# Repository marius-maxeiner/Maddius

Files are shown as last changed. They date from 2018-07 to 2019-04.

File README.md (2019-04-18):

# Maddius
_English:_

ALPHA

The Maddius Main, built by Marius and Eddie.

Maddius is an Open - Source midi controller, you can build your own.
The idea is to share our code, 3d files and bill of material with the internet so the topic of midi controllers can be better understood.
Maddius is split in different Modules you can build so it fits with your setup, the i2c signal gets translated to midi by the Teensy 3.6 inside of the Maddius Main.
If you want more informations on the expansions for Maddius feel free to look inside thier respective folder.
Because the Maddius Main is the converter to Midi we recommend to start there.

Ever got tired of over complicated Dmx Controller or Light Setups in your favorite bar or club? You are working sometimes as a hobby technican? Dont worry no more, even better, impress your boss and show them your newly built Maddius Main! Controlling and adapting to your setup! Need 8 Fader and Blind Buttons? No problem! Need another expansions with scene selection or bank switching? We got you covered. Only want to build your own Midi Controller? Maybe our code is just for you!
Want to know how to wire a controller? Check out our diagramms!

We hope you have fun building and coding!

Greetings, Marius & Eddie.

_German:_

ALPHA

Der Maddius Main, gebaut von Marius und Eddie.

Maddius ist ein Open - Source Midi Controller, den du dir selbst bauen kannst.
Die Idee hinter der Sache ist es, unseren Code, 3D Modelle und eine Liste der gebrauchten Materialen im Internet zu veröffentlichen, damit das Thema Midi-Controller besser verstanden werden kann. Maddius ist aufgeteilt in verschiedene Module, die mit einer i2c Verbindung kommunizieren. Das Herzstück bildet hierbei der Maddius Main, da er alle Signale mithilfe eines Teensy 3.6 zu Midi konvertiert.
Wenn du mehr Informationen zu den einzelnen Modulen haben möchtest, kannst du dich gerne in den dazugehörigen Ordnern umsehen.
Allerdings empfehlen wir beim Maddius Main zu starten.

Bist du genervt von komplizierten Dmx Controllern oder Licht Setup´s in deiner geliebten Bar oder deines beliebeten Club´s? Arbeitest du manchmal als ein Hobby-Techniker? Mach dir keinen Kopf, noch besser, beeindrucke deinen Chef und zeige ihm deinen neu gebauten Maddius DMX Kontroller der Anpassbar auf dein Setup ist! Brauchst du 8 Fader und Blind Buttons? Kein Problem! Brauchst du Erweiterungen und auswählbare Scenen oder Layer switching? Wir haben alles für dich da. Möchtest du nur deinen eigenen Midi Controller bauen? Dann ist vielleicht unser Code genau das richtige für dich!
Möchtest du nur wissen, wie ein Controller verkabelt wird? Check unsere Diagramme!

Wir hoffen du hast Spaß beim nachbauen und programmieren!

Grüße, Marius & Eddie.

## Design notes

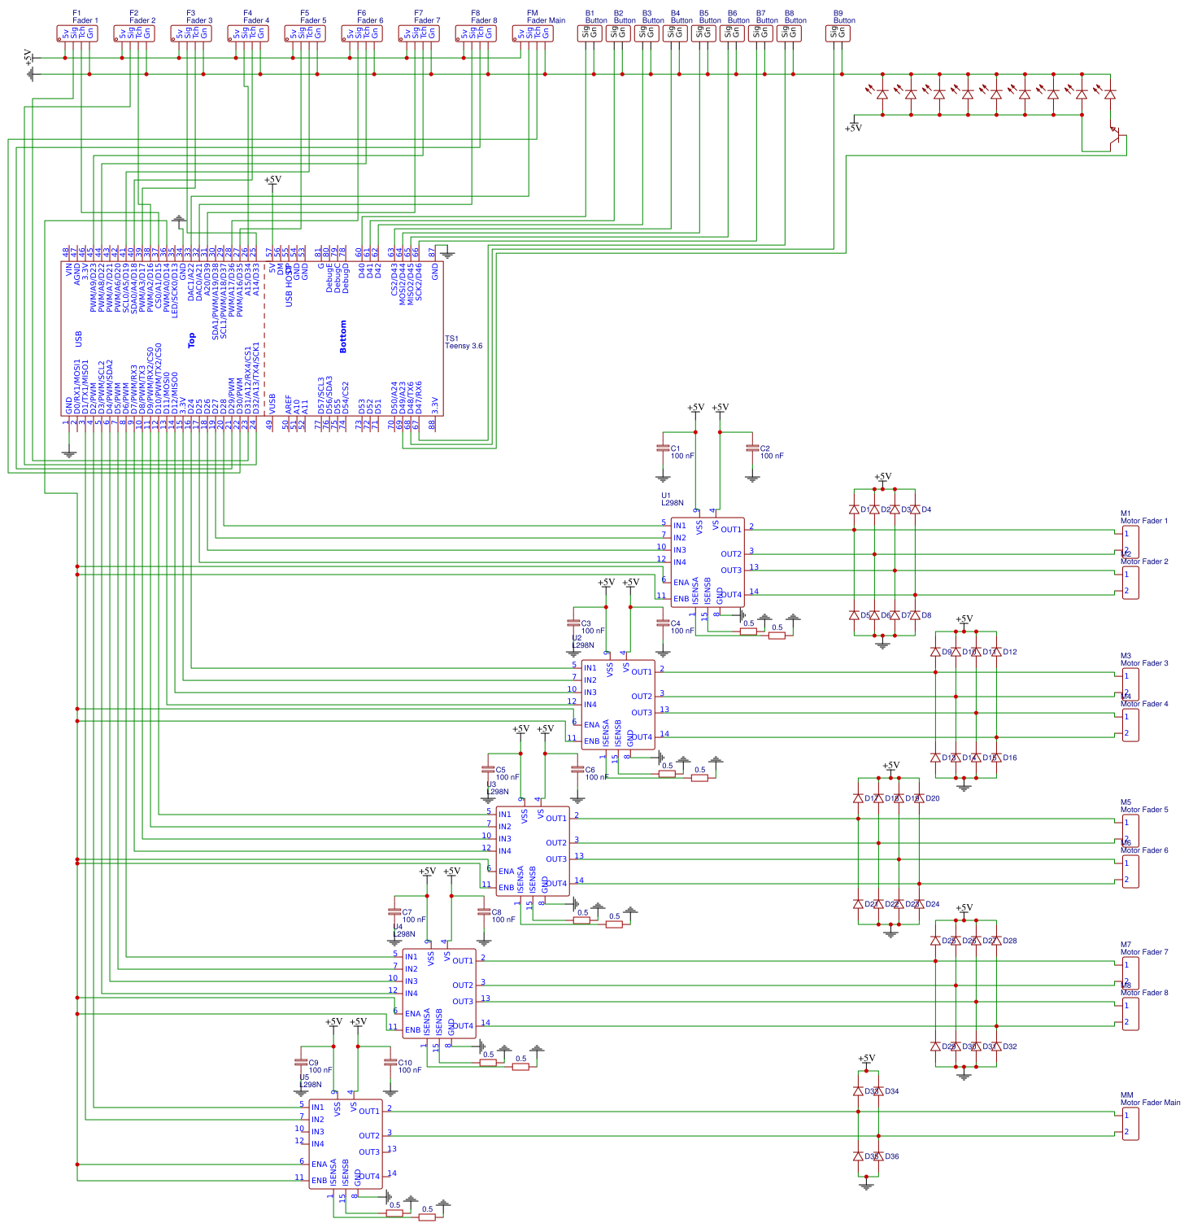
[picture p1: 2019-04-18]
Main/Schematic_Maddius-Main.png

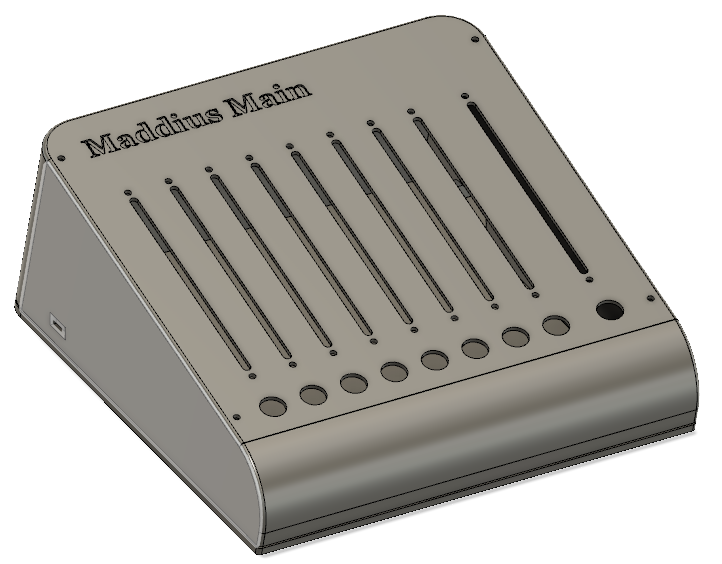
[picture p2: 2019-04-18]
Main/Maddius Main.png

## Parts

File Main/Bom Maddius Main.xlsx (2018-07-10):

BOM | Maddius Main
 | Name | Link | Price
 | Motor Fader | https://www.thomann.de/de/yamaha_ls_901vmotorised_fader.htm?glp=1 | 19.90 €
 | Teensy 3.6 | https://www.amazon.de/Teensy-3-6/dp/B01MG2PYYP | 42.99 €
 | Buttons | https://www.amazon.de/Larcele-Wasserdicht-Drücken-Druckknöpfe-JSANKG-02/dp/B075YPVY56?s=aps | 17.99 €
 | Motor Controller | https://www.amazon.de/Channel-Treiberplatine-Geschwindigkeit-Stepper-Ladicha/dp/B077MBSF2N?s=diy

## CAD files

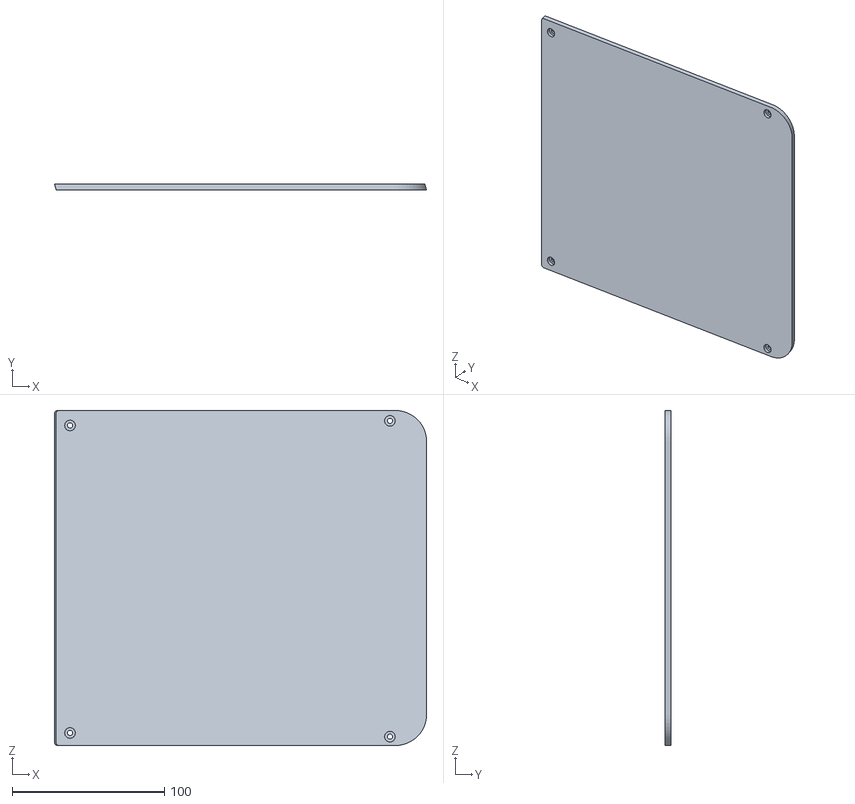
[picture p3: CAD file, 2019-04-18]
Main/3D Models/Maddius Main Base.stl
244.1 x 4.00 x 219.9

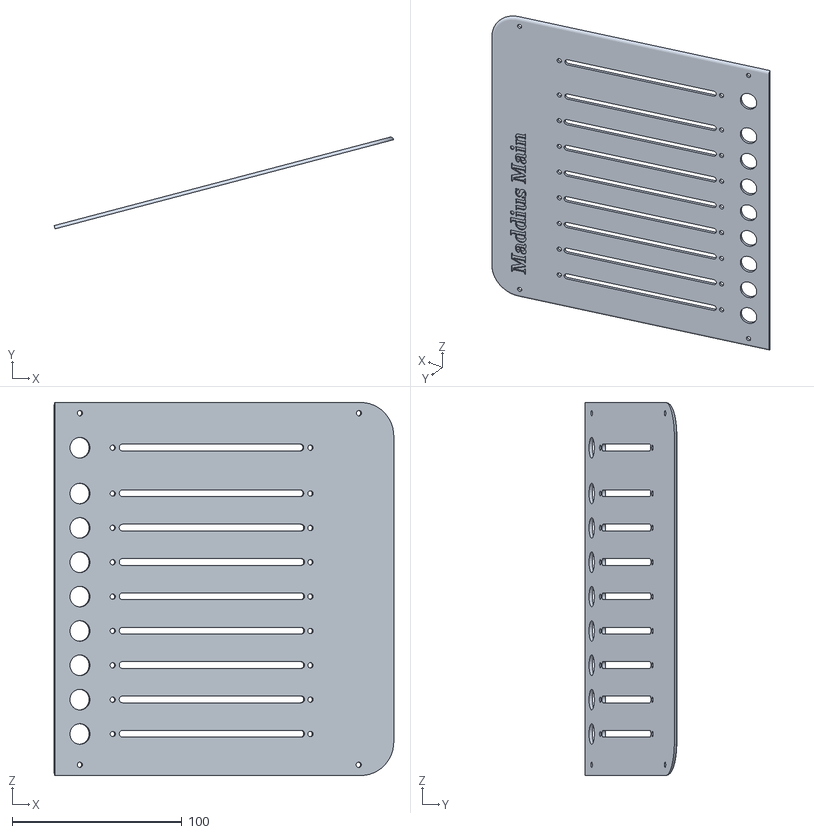
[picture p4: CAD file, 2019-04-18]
Main/3D Models/Maddius Main Cover.stl
200.2 x 54.1 x 219.9

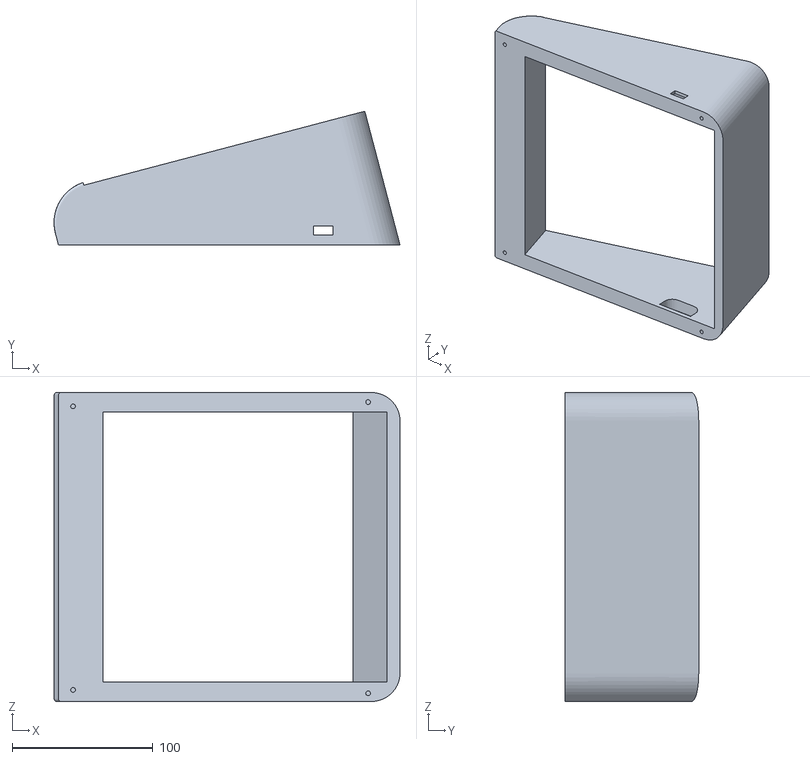
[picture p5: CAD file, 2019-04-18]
Main/3D Models/ Maddius Main Case.stl
246.1 x 95.0 x 219.9

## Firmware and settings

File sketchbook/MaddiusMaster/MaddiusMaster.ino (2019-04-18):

<<<<<<< HEAD
/* Belegung	Pin Name	Pin Number	Spice Number
	VBAT	1	1
	5V	2	2
	USBD2-	3	3
	USBD2+	4	4
	USBD1-	5	5
	USBD1+	6	6
Fader 5	A10	7	7
Fader 6	A11	8	8
	GND	9	9
Btn 1	0	10	10
Btn 2	1	11	11
Btn LED 1	2	12	12
Btn LED 2	3	13	13
Btn LED 3	4	14	14
Btn LED 4	5	15	15
Btn LED 5	6	16	16
Btn LED 6	7	17	17
Btn LED 7	8	18	18
Btn LED 8	9	19	19
Btn LED 9	10	20	20
Motor 1 B	11	21	21
Motor 1 A	12	22	22
Motor 5 B	40	23	23
Motor 2 B	24	24	24
Motor 3 B	25	25	25
Motor 3 A	26	26	26
Motor 4 A	27	27	27
Motor 4 B	28	28	28
Touch 8	29	29	29
Touch 9	30	30	30
Fader 1	31/A12	31	31
Fader 2	32/A13	32	32
Motor 5 A	41	33	33
Motor 6 A	42	34	34
Motor 6 B	43	35	35
Motor 7 B	44	36	36
Motor 7 B	45	37	37
Motor 8 A	46	38	38
Motor 8 B	47	39	39
Motor 9 B	48	40	40
Btn 3	49/A23	41	41
Btn 4	50/A24	42	42
Motor 9 A	51	43	43
Btn 5	52	44	44
Btn 6	53	45	45
Btn 7	54	46	46
Btn 8	55	47	47
I2C	56	48	48
Standby	33/A14	49	49
Motor 2 A	34/A15	50	50
	35/A16	51	51
Motor Speed	36/A17	52	52
I2C	37/A18	53	53
I2C	38/A19	54	54
Fader 7	39/A20	55	55
Fader 3	A21	56	56
Fader 4	A22	57	57
I2C	57	58	58
Power/Sys LED	13 (LED)	59	59
Fader 8	14/A0	60	60
Touch 1	15/A1	61	61
Touch 2	16/A2	62	62
Touch 3	17/A3	63	63
Touch 4	18/A4	64	64
Touch 5	19/A5	65	65
Fader 9	20/A6	66	66
Btn 9	21/A7	67	67
Touch 6	22/A8	68	68
Touch 7	23/A9	69	69
	3V3	70	70
	AGND	71	71
Main Power	VIN	72	72
	GND	73	73
	VUSB	74	74
	PRGM	75	75
	RESET	76	76
	AREF	77	77
	DBGEN	78	78
	SWCLK	79	79
	SWDIO	80	80
	MT1	81	81
	MT2	82	82
*/
=======
//This is the Code for the Maddius Main Controller, built by Marius and Eddie.
//We hope you have fun editing and using this Code for yourself.

>>>>>>> 7a19cae50ffcc8ba62d0dede8335053ce0ca0dc0


//________Including Library´s____________
#include <Wire.h> // I2C
// #include <ClickEncoder.h>
#include <TimerOne.h>
#include <ControlPanel.h>

//________Setting Defines________________
#define DEVMODE true

//________Setting Pins___________________
//MotorA motor1(3, 4, 2);

// Button Digi/LED PWM // 
// B1 0 / 2
Button button1(0);
// B2 1 / 3
Button button2(1);
/*// B3 55 / 4
Button button3(55);
// B4 14 / 31
Button button4(14);
// B5 35 / 6 // A16 / 
Button button5(35);
// B6 34 / 7 // A15 /
Button button6(34);
// B7 39 / 8 // A20
Button button7(39);
// B8 49 / 9 // A23
Button button8(49);
// B9 50 / 10 // A24
Button button9(50);*/

// Motor

// FADER Analog / Touch
// F1
Fader fader1(31, 15, new MotorB(11, 12, 36, 33)); // , new MotorPWM(2, 3)
// F2
Fader fader2(32, 16, new MotorB(34, 24, 36, 33));
// F3
Fader fader3(A21, 17, new MotorB(25, 26, 36, 33));
// F4
Fader fader4(A22, 18, new MotorB(27, 28, 36, 33));
// F5
Fader fader5(A10, 19, new MotorB(40, 41, 36, 33));
// F6
Fader fader6(A11, 22, new MotorB(42, 43, 36, 33));
// F7 
Fader fader7(39, 23, new MotorB(44, 45, 36, 33));
// F8
Fader fader8(14, 29, new MotorB(46, 47, 36, 33));
// F9
Fader fader9(20, 30, new MotorB(48, 51, 36, 33));

// Motoren PWM: 52
// M1 12 / 11

// Fader 1 fader1(10, 30, new MotorA(3, 4, 2));

// Fader fader2(A2, A3); // , new MotorPWM(4, 5)



//int pwmCircleCount = 0;
//byte motorspeed = 0;

// ClickEncoder* encoder;
// int16_t last, value;

// int16_t mouseTimeout = 0;

// JoyStick* joy1;
void setup() {
<<<<<<< HEAD
  // encoder = new ClickEncoder(A20, A19, A18);
  // joy1 =  new JoyStick(A17,A16);
  // put your setup code here, to run once
  if (DEVMODE) {
    pinMode(LED_BUILTIN, OUTPUT);
    pinMode(LED_BUILTIN, INPUT_PULLUP);
    // Serial.begin(57600); // start serial for output
=======
  encoder = new ClickEncoder(A20, A19, A18);
  joy1 =  new JoyStick(A17,A16);
  if (DEVMODE) {
    pinMode(LED_BUILTIN, OUTPUT);
    pinMode(LED_BUILTIN, INPUT_PULLUP);
    pinMode(52, OUTPUT);
    // ___SERIAL_BEGIN____
    Serial.begin(57600);
>>>>>>> 7a19cae50ffcc8ba62d0dede8335053ce0ca0dc0
    // Serial.println("Start Maddius Master");
  }

  // __Init Midi read functions__
  usbMIDI.setHandleNoteOff(myNoteOff);
  usbMIDI.setHandleNoteOn(myNoteOn);
  usbMIDI.setHandleAfterTouchPoly(myAfterTouchPoly);
  usbMIDI.setHandleControlChange(myControlChange);

  //fader1._valueTarget = 800;

  // Timer1.initialize(1000);
  // Timer1.attachInterrupt(timerIsr);
  // Motoren PWM: 52
// M1 12 / 11
  /* byte _motorUpIOPin = 11;
   byte _motorDownIOPin = 12;
   byte _motorSpeedPWM = 52;
  delay(1000);
  // Motor Test
  pinMode(_motorUpIOPin, OUTPUT);
  pinMode(_motorDownIOPin, OUTPUT);
  analogWrite(_motorSpeedPWM , 150);
  delay(1000);
  digitalWrite(_motorUpIOPin, HIGH);
  digitalWrite(_motorDownIOPin, LOW);
  delay(1000);
  digitalWrite(_motorUpIOPin, LOW);
  digitalWrite(_motorDownIOPin, HIGH);
  delay(1000);
  digitalWrite(_motorUpIOPin, HIGH);
  digitalWrite(_motorDownIOPin, LOW);
  delay(1000);
  digitalWrite(_motorUpIOPin, LOW);
  digitalWrite(_motorDownIOPin, HIGH);
  delay(1000);*/



}

/* void timerIsr() {
  // encoder->service();
  
  if(mouseTimeout > 10){
    joy1->update();
    if(joy1->_humanChanged){
      Serial.print(" X: ");
      Serial.print(joy1->_xValue);
      Serial.print(" Y: ");
      Serial.println(joy1->_yValue);
      usbMIDI.sendControlChange(96, joy1->_xValue >> 3, 1);
      usbMIDI.sendControlChange(97, joy1->_yValue >> 3, 1);
    }
    mouseTimeout = 0;
  }
  mouseTimeout++;
} */
void loop() {

  
  // BUTTON UPDATE
  short b1 = button1.update();
  short b2 = button2.update();
  /*short b3 = button3.update();
  short b4 = button4.update();
  short b5 = button5.update();
  short b6 = button6.update();
  short b7 = button7.update();
  short b8 = button8.update();
  short b9 = button9.update();*/

  // FADER UPDATE




  short f1 = fader1.update();
          //Serial.println("f1_humanChanged");
        //Serial.println(fader1.readTouch());



  short f2 = fader2.update();
  short f3 = fader3.update();
  short f4 = fader4.update();
  short f5 = fader5.update();
  short f6 = fader6.update();
  short f7 = fader7.update();
  short f8 = fader8.update();
  short f9 = fader9.update();

  

  byte val1 = f1 / 8;
  byte val2 = f2 / 8;
  byte val3 = f3 / 8;
  byte val4 = f4 / 8;
  byte val5 = f5 / 8;
  byte val6 = f6 / 8;
  byte val7 = f7 / 8;
  byte val8 = f8 / 8;
  byte val9 = f9 / 8;
  
  /*if (DEVMODE) {
      //Serial.println(fader1.readAnalog());
      //Serial.println(touchRead(15));

     if(button1._humanChanged){
        Serial.println("button1._humanChanged");
        Serial.println(b1);
        usbMIDI.sendControlChange(64, b1, 1);
      }
      if(button2._humanChanged){
        Serial.println("button2._humanChanged");
        Serial.println(b2);
        usbMIDI.sendControlChange(65, b2, 1);
      }
      /*if(button3._humanChanged){
        Serial.println("button3._humanChanged");
        Serial.println(b3);
        usbMIDI.sendControlChange(66, b3, 1);
      }
      if(button4._humanChanged){
        Serial.println("button4._humanChanged");
        Serial.println(b4);
        usbMIDI.sendControlChange(67, b4, 1);
      }
      if(button5._humanChanged){
        Serial.println("button5._humanChanged");
        Serial.println(b5);
        usbMIDI.sendControlChange(68, b5, 1);
      }
      if(button6._humanChanged){
        Serial.println("button6._humanChanged");
        Serial.println(b6);
        usbMIDI.sendControlChange(69, b6, 1);
      }
     if(button7._humanChanged){
        Serial.println("button7._humanChanged");
        Serial.println(b7);
        usbMIDI.sendControlChange(70, b7, 1);
      }
      if(button8._humanChanged){
        Serial.println("button8._humanChanged");
        Serial.println(b8);
        usbMIDI.sendControlChange(71, b8, 1);
      }
      if(button9._humanChanged){
        Serial.println("button9._humanChanged");
        Serial.println(b9);
        usbMIDI.sendControlChange(72, b9, 1);
        _humanChanged = false;
      }*/
// Serial.print("T1: ");
// Serial.println(fader1.readTouch());
// Serial.print("F1: ");
//Serial.println(fader1.readAnalog());


      // FADER 
      /*if(fader1._humanChanged){
        Serial.println("f1_humanChanged");
        Serial.println(fader1.readTouch());
        // Serial.println(f1);
        Serial.println(fader1.readAnalog());
        usbMIDI.sendControlChange(12, val1, 1);
      }
     if(fader2._humanChanged){
        Serial.println("f2_humanChanged");
        Serial.println(fader2.readTouch());
        Serial.println(f2);
        Serial.println(fader2._valueTarget);
        usbMIDI.sendControlChange(13, val2, 1);
      }
      if(fader3._humanChanged){
        Serial.println("f3_humanChanged");
        Serial.println(fader3.readTouch());
        Serial.println(f3);
        Serial.println(fader3._valueTarget);
        usbMIDI.sendControlChange(14, val3, 1);
      }
      if(fader4._humanChanged){
        Serial.println("f4_humanChanged");
        Serial.println(fader4.readTouch());
        Serial.println(f4);
        Serial.println(fader4._valueTarget);
        usbMIDI.sendControlChange(15, val4, 1);
      }
      if(fader5._humanChanged){
        Serial.println("f5_humanChanged");
        Serial.println(fader5.readTouch());
        Serial.println(f5);
        Serial.println(fader5._valueTarget);
        usbMIDI.sendControlChange(16, val5, 1);
      }
      if(fader6._humanChanged){
        Serial.println("f6_humanChanged");
        Serial.println(fader6.readTouch());
        Serial.println(f6);
        Serial.println(fader6._valueTarget);
        usbMIDI.sendControlChange(17, val6, 1);
      }
      if(fader7._humanChanged){
        Serial.println("f7_humanChanged");
        Serial.println(fader7.readTouch());
        Serial.println(f7);
        Serial.println(fader7._valueTarget);
        usbMIDI.sendControlChange(18, val7, 1);
      }
      if(fader8._humanChanged){
        Serial.println("f8_humanChanged");
        Serial.println(fader8.readTouch());
        Serial.println(f8);
        Serial.println(fader8._valueTarget);
        usbMIDI.sendControlChange(19, val8, 1);
      }
      if(fader9._humanChanged){
        Serial.println("f9_humanChanged");
        Serial.println(fader9.readTouch());
        Serial.println(f9);
        Serial.println(fader9._valueTarget);
        usbMIDI.sendControlChange(20, val9, 1);
      }
  }

  // value += encoder->getValue();
  
  /*if (value != last) {
    last = value;
    Serial.print("Encoder Value: ");
    Serial.println(value);
  }*/

  /* ClickEncoder::Button b = encoder->getButton();
  if (b != ClickEncoder::Open) {
    Serial.print("Button: ");
    #define VERBOSECASE(label) case label: Serial.println(#label); break;
    switch (b) {
      VERBOSECASE(ClickEncoder::Pressed);
      VERBOSECASE(ClickEncoder::Held)
      VERBOSECASE(ClickEncoder::Released)
      VERBOSECASE(ClickEncoder::Clicked)
      case ClickEncoder::DoubleClicked:
          Serial.println("ClickEncoder::DoubleClicked");
          encoder->setAccelerationEnabled(!encoder->getAccelerationEnabled());
          Serial.print("  Acceleration is ");
          Serial.println((encoder->getAccelerationEnabled()) ? "enabled" : "disabled");
        break;
    }
  } */
  //int poti = analogRead(A11);
  //Serial.println(poti >> 2);
  // analogWrite(2, poti >> 2);
  
  /*int btn = digitalRead(56);
  int x = analogRead(33);
  int y = analogRead(34);
  Serial.print("B:");
  Serial.print(btn);
  Serial.print(" X: ");
  Serial.print(x);
  Serial.print(" Y: ");
  Serial.println(y);*/
  if(fader1._humanChanged){
  usbMIDI.sendControlChange(12, val1, 1);
  }
  if(fader2._humanChanged){
  usbMIDI.sendControlChange(13, val2, 1);
  }
  if(fader3._humanChanged){
  usbMIDI.sendControlChange(14, val3, 1);
  }
  if(fader4._humanChanged){
  usbMIDI.sendControlChange(15, val4, 1);
  }
  if(fader5._humanChanged){
  usbMIDI.sendControlChange(16, val5, 1);
  }
  if(fader6._humanChanged){
  usbMIDI.sendControlChange(17, val6, 1);
  }
  if(fader7._humanChanged){
  usbMIDI.sendControlChange(18, val7, 1);
  }
  if(fader8._humanChanged){
  usbMIDI.sendControlChange(19, val8, 1);
  }
  if(fader9._humanChanged){
  usbMIDI.sendControlChange(20, val9, 1);
  }


  // Serial.println(a1);
  // Serial.println(pos[poscount]);
  // Read MIDI from USB 
  while (usbMIDI.read()) {
    // read & ignore incoming messages
    Serial.println("read");
    Serial.println(usbMIDI.getType());
    Serial.println(usbMIDI.getChannel());
  }
 }

 void myNoteOn(byte channel, byte note, byte velocity){
  if (DEVMODE) {
    Serial.println("myNoteOn");
    Serial.println(channel);
    Serial.println(note);
    Serial.println(velocity);
  }
 }
 void myNoteOff(byte channel, byte note, byte velocity){
  if (DEVMODE) {
    Serial.println("myNoteOff");
    Serial.println(channel);
    Serial.println(note);
    Serial.println(velocity);
  }
 }
 void myAfterTouchPoly(byte channel, byte note, byte velocity){
  if (DEVMODE) {
    Serial.println("myAfterTouchPoly");
    Serial.println(channel);
    Serial.println(note);
    Serial.println(velocity);
  }
 }
 void myControlChange(byte channel, byte control, byte value){
  if (DEVMODE) {
    Serial.println("myControlChange");
    Serial.println(channel);
    Serial.println(control);
    Serial.println(value);
  }
  if(control == 12){
    fader1._valueTarget = value * 8;
  }
  if(control == 13){
    fader2._valueTarget = value * 8;
  }
  if(control == 14){
    fader3._valueTarget = value * 8;
  }
  if(control == 15){
    fader4._valueTarget = value * 8;
  }
  if(control == 16){
    fader5._valueTarget = value * 8;
  }
  if(control == 17){
    fader6._valueTarget = value * 8;
  }
  if(control == 18){
    fader7._valueTarget = value * 8;
  }
  if(control == 19){
    fader8._valueTarget = value * 8;
  }
  if(control == 20){
    fader9._valueTarget = value * 8;
  }
 }

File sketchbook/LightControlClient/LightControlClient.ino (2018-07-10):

// Light Control Client i2c
#define DEVMODE true

#define CHANNELCOUNT 3

#define I2CADRESS 8

#define PotiMulti 0.2925
#define PotiTolerance 2

#include <Wire.h>

struct channel_def
{
    byte type;
    byte d_i;
    byte d_o;
    byte a_i;
    byte a_o;
    byte inputState;
    byte inputLastState;
    byte incomingValue;
    byte incomingLastValue;
    byte outgoingValue;
    byte outgoingLastValue;
};
typedef struct channel_def Channel;
/* TYPES
 * 1 : Push Button
 * 2 : Reverse Button
 */

Channel channel[CHANNELCOUNT] = {
    {2, 11, 0, 0, 0, 0, 0, 0, 0, 0, 0},
    {3, 12, 2, 0, 0, 0, 0, 0, 0, 0, 0},
    {10, 0, 0, 1, 0, 0, 0, 0, 0, 0, 0}};

bool init1 = false;

void setup()
{
    Wire.begin(I2CADRESS);
    // register events
    Wire.onRequest(requestEvent);
    Wire.onReceive(receiveEvent);
    if (DEVMODE)
    {
        Serial.begin(38400); // start serial for output
        Serial.println("Start Slave");
    }
    for (int chanelIndex = 0; chanelIndex < CHANNELCOUNT; chanelIndex++)
    {
        if (channel[chanelIndex].d_i > 0)
        {
            pinMode(channel[chanelIndex].d_i, INPUT_PULLUP);
        }
        if (channel[chanelIndex].d_o > 0)
        {
            pinMode(channel[chanelIndex].d_o, OUTPUT);
        }
    }
}

void loop()
{
    bool onKeyUp;
    bool dState;
    int aState;
    byte tmp0;
    byte out;
    for (int chanelIndex = 0; chanelIndex < CHANNELCOUNT; chanelIndex++)
    {
        onKeyUp = false;
        switch (channel[chanelIndex].type)
        {
        case 1:
            dState = digitalRead(channel[chanelIndex].d_i);
            if (!dState)
            {
                channel[chanelIndex].inputState = 255;
            }
            else
            {
                channel[chanelIndex].inputState = 0;
            }
            out = channel[chanelIndex].inputState;
            if (channel[chanelIndex].d_o > 0)
            {
                if (channel[chanelIndex].incomingValue > 127)
                {
                    digitalWrite(channel[chanelIndex].d_o, HIGH);
                }
                else
                {
                    digitalWrite(channel[chanelIndex].d_o, LOW);
                }
            }
            break;
        case 2:
            onKeyUp = true;
        case 3:
            dState = digitalRead(channel[chanelIndex].d_i);
            if (!dState)
            {
                channel[chanelIndex].inputState = 255;
            }
            else
            {
                channel[chanelIndex].inputState = 0;
            }
            if (channel[chanelIndex].inputLastState != channel[chanelIndex].inputState)
            {
                out = channel[chanelIndex].outgoingValue;
                Serial.println((onKeyUp && channel[chanelIndex].inputLastState == 255));
                Serial.println((!onKeyUp && channel[chanelIndex].inputState == 255));
                if ((onKeyUp && channel[chanelIndex].inputLastState == 255) || (!onKeyUp && channel[chanelIndex].inputLastState == 0))
                {
                    if (channel[chanelIndex].outgoingValue > 127)
                    {
                        out = 0;
                    }
                    else
                    {
                        out = 255;
                    }
                }
            }
            if (channel[chanelIndex].d_o > 0)
            {
                if (channel[chanelIndex].incomingValue > 127)
                {
                    digitalWrite(channel[chanelIndex].d_o, HIGH);
                }
                else
                {
                    digitalWrite(channel[chanelIndex].d_o, LOW);
                }
            }
            break;
        case 10:
            aState = analogRead(channel[chanelIndex].a_i);
            // Serial.println(aState);
            channel[chanelIndex].inputState = map(aState, 0, 872, 0, 255);
            if (channel[chanelIndex].inputState < PotiTolerance)
            {
                channel[chanelIndex].inputState = 0;
            }
            else if (channel[chanelIndex].inputState > (255 - PotiTolerance))
            {
                channel[chanelIndex].inputState = 255;
            }
            else
            {
                // distance
                tmp0 = fabs(channel[chanelIndex].inputState - channel[chanelIndex].outgoingValue);
                if (tmp0 <= PotiTolerance)
                {
                    channel[chanelIndex].inputState = channel[chanelIndex].outgoingValue;
                }
            }
            out = channel[chanelIndex].inputState;
            break;
        default:
            out = channel[chanelIndex].inputState;
            Serial.println("No such Type");
        }
        if (channel[chanelIndex].inputState != channel[chanelIndex].inputLastState)
        {
            if (DEVMODE)
            {
                printStatus(chanelIndex, "mainloop");
            }
            channel[chanelIndex].inputLastState = channel[chanelIndex].inputState;
            channel[chanelIndex].outgoingValue = out;
        }
    }
}

void printStatus(int chanelIndex, char type[8])
{
    Serial.print("###  ");
    Serial.print(chanelIndex);
    Serial.print("  ###  ");
    Serial.print(type);
    Serial.println("  ###");
    Serial.print("inputState: ");
    Serial.print(channel[chanelIndex].inputLastState);
    Serial.print(" -> ");
    Serial.println(channel[chanelIndex].inputState);
    Serial.print("incomingValue: ");
    Serial.print(channel[chanelIndex].incomingLastValue);
    Serial.print(" -> ");
    Serial.println(channel[chanelIndex].incomingValue);
    Serial.print("outgoingValue: ");
    Serial.print(channel[chanelIndex].outgoingLastValue);
    Serial.print(" -> ");
    Serial.println(channel[chanelIndex].outgoingValue);
    // delay(100);
}

// function that executes whenever data is received from master
// this function is registered as an event, see setup()
void receiveEvent(int howMany)
{
    for (int chanelIndex = 0; chanelIndex < CHANNELCOUNT; chanelIndex++)
    {
        channel[chanelIndex].incomingValue = Wire.read();
        if (channel[chanelIndex].incomingValue != channel[chanelIndex].incomingLastValue)
        {
            channel[chanelIndex].outgoingValue = channel[chanelIndex].incomingValue;
            if (DEVMODE)
            {

                printStatus(chanelIndex, "incoming");
            }
            channel[chanelIndex].incomingLastValue = channel[chanelIndex].incomingValue;
        }
    }
}

void requestEvent()
{
    for (int chanelIndex = 0; chanelIndex < CHANNELCOUNT; chanelIndex++)
    {
        Wire.write(channel[chanelIndex].outgoingValue);
        if (channel[chanelIndex].outgoingValue != channel[chanelIndex].outgoingLastValue)
        {
            if (DEVMODE)
            {
                printStatus(chanelIndex, "outgoing");
            }
            channel[chanelIndex].outgoingLastValue = channel[chanelIndex].outgoingValue;
        }
    }
}

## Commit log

2018-07-10 BOM Maddius Main
    Bill of Material
    [Bom Maddius Main.xlsx]
2018-07-10 3D Files Added
    3d Files
    [Maddius Main Case.stl, Maddius Main Base.stl, Maddius Main Cover.stl]
2018-07-10 3D Modelle Verschoben
    [Maddius Main Case.stl, Maddius Main Base.stl, Maddius Main Cover.stl]
2018-07-10 Ordnung und Readme
    [Maddius Main Case.stl, Maddius Main Base.stl, Maddius Main Cover.stl]
2018-07-16 Schematics and Readme Changes
2018-07-16 Updated Schematic
